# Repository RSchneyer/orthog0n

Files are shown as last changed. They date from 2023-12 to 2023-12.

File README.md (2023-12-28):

# orthog0n

orthog0n keyboard on grey deskmat

The orthog0n is the last keyboard I'll probably design (for the forseeable future). The RGBKB Zen that I had been using for games for like 5 years bit the dust, so I decided to throw together something I had always wanted to get around to making.

As usual, I take no responsibility for anything that doesn't work, or goes wrong when you try to build or use this board. Good luck!

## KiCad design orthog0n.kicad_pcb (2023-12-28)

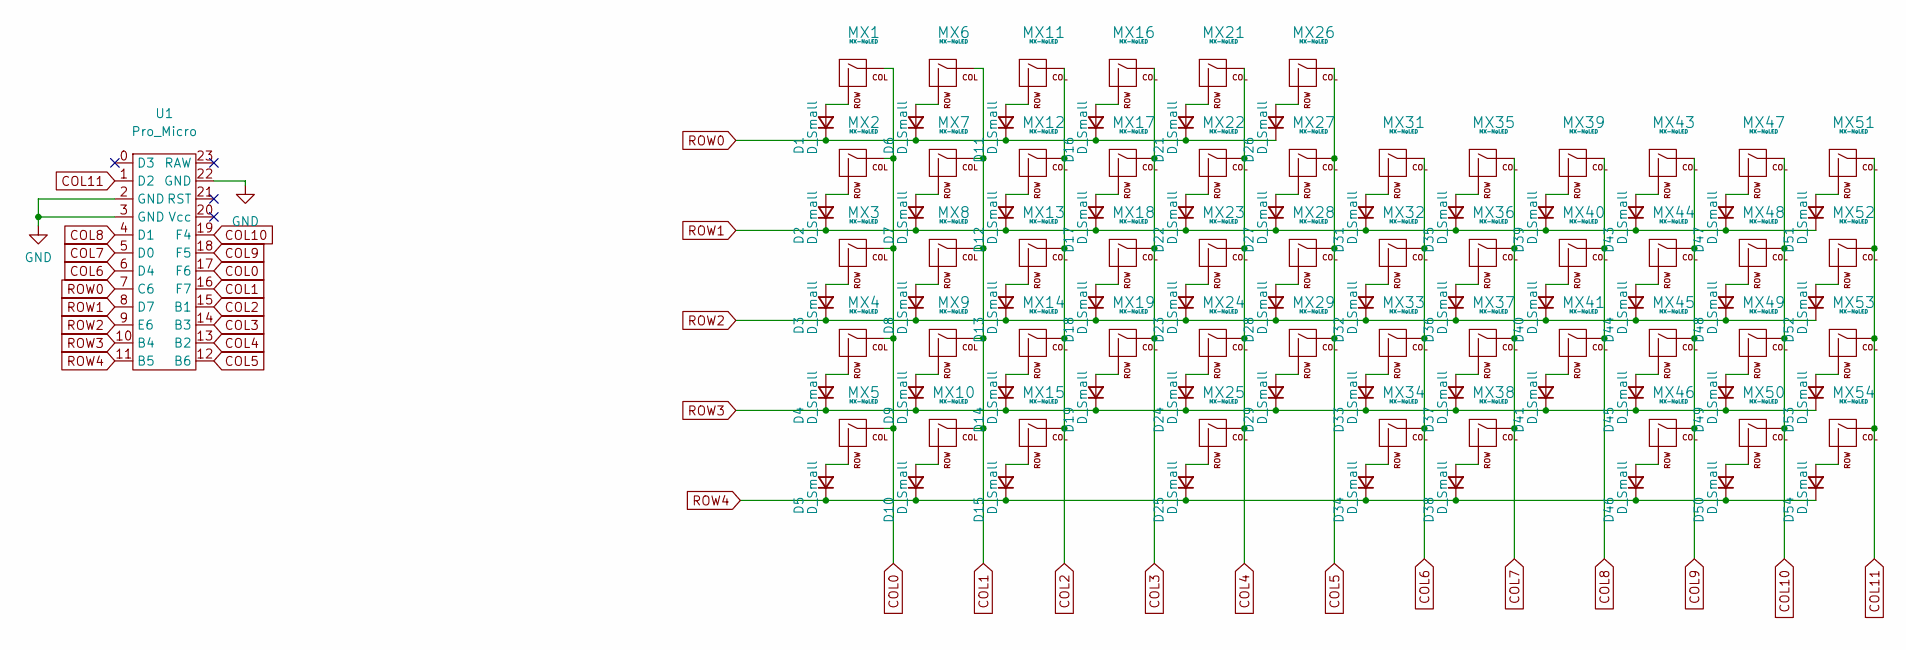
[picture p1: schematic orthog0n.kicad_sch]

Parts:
D1, D2, D3, D4, D5, D6, D7, D8, D9, D10, D11, D12, D13, D14, D15, D16, D17, D18, D19, D21, D22, D23, D24, D25, D26, D27, D28, D29, D31, D32, D33, D34, D35, D36, D37, D38, D39, D40, D41, D43, D44, D45, D46, D47, D48, D49, D50, D51, D52, D53, D54: D_Small; D_DO-35_SOD27_P10.16mm_Horizontal
MX1, MX2, MX3, MX4, MX5, MX15, MX46, MX51, MX52, MX53, MX54: MX-NoLED; SW_Cherry_MX_1.50u_PCB
MX6, MX7, MX8, MX9, MX10, MX11, MX12, MX13, MX14, MX16, MX17, MX18, MX19, MX21, MX22, MX23, MX24, MX26, MX27, MX28, MX29, MX31, MX32, MX33, MX34, MX35, MX36, MX37, MX39, MX40, MX41, MX43, MX44, MX45, MX47, MX48, MX49, MX50: MX-NoLED; SW_Cherry_MX_1.00u_PCB
MX25, MX38: MX-NoLED; SW_Cherry_MX_2.00u_PCB
U1: Pro_Micro; pro_micro

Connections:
COL0: MX1.1 (COL), MX2.1 (COL), MX3.1 (COL), MX4.1 (COL), MX5.1 (COL), U1.17 (F6)
COL1: MX6.1 (COL), MX7.1 (COL), MX8.1 (COL), MX9.1 (COL), MX10.1 (COL), U1.16 (F7)
COL2: MX11.1 (COL), MX12.1 (COL), MX13.1 (COL), MX14.1 (COL), MX15.1 (COL), U1.15 (B1)
COL3: MX16.1 (COL), MX17.1 (COL), MX18.1 (COL), MX19.1 (COL), U1.14 (B3)
COL4: MX21.1 (COL), MX22.1 (COL), MX23.1 (COL), MX24.1 (COL), MX25.1 (COL), U1.13 (B2)
COL5: MX26.1 (COL), MX27.1 (COL), MX28.1 (COL), MX29.1 (COL), U1.12 (B6)
COL6: MX31.1 (COL), MX32.1 (COL), MX33.1 (COL), MX34.1 (COL), U1.6 (D4)
COL7: MX35.1 (COL), MX36.1 (COL), MX37.1 (COL), MX38.1 (COL), U1.5 (D0)
COL8: MX39.1 (COL), MX40.1 (COL), MX41.1 (COL), U1.4 (D1)
COL9: MX43.1 (COL), MX44.1 (COL), MX45.1 (COL), MX46.1 (COL), U1.18 (F5)
COL10: MX47.1 (COL), MX48.1 (COL), MX49.1 (COL), MX50.1 (COL), U1.19 (F4)
COL11: MX51.1 (COL), MX52.1 (COL), MX53.1 (COL), MX54.1 (COL), U1.1 (D2)
GND: U1.2 (GND), U1.3 (GND), U1.22 (GND)
unnamed: D1.2 (A), MX1.2 (ROW)
unnamed: D2.2 (A), MX2.2 (ROW)
unnamed: D3.2 (A), MX3.2 (ROW)
unnamed: D4.2 (A), MX4.2 (ROW)
unnamed: D5.2 (A), MX5.2 (ROW)
unnamed: D6.2 (A), MX6.2 (ROW)
unnamed: D7.2 (A), MX7.2 (ROW)
unnamed: D8.2 (A), MX8.2 (ROW)
unnamed: D9.2 (A), MX9.2 (ROW)
unnamed: D10.2 (A), MX10.2 (ROW)
unnamed: D11.2 (A), MX11.2 (ROW)
unnamed: D12.2 (A), MX12.2 (ROW)
unnamed: D13.2 (A), MX13.2 (ROW)
unnamed: D14.2 (A), MX14.2 (ROW)
unnamed: D15.2 (A), MX15.2 (ROW)
unnamed: D16.2 (A), MX16.2 (ROW)
unnamed: D17.2 (A), MX17.2 (ROW)
unnamed: D18.2 (A), MX18.2 (ROW)
unnamed: D19.2 (A), MX19.2 (ROW)
unnamed: D21.2 (A), MX21.2 (ROW)
unnamed: D22.2 (A), MX22.2 (ROW)
unnamed: D23.2 (A), MX23.2 (ROW)
unnamed: D24.2 (A), MX24.2 (ROW)
unnamed: D25.2 (A), MX25.2 (ROW)
unnamed: D26.2 (A), MX26.2 (ROW)
unnamed: D27.2 (A), MX27.2 (ROW)
unnamed: D28.2 (A), MX28.2 (ROW)
unnamed: D29.2 (A), MX29.2 (ROW)
unnamed: D31.2 (A), MX31.2 (ROW)
unnamed: D32.2 (A), MX32.2 (ROW)
unnamed: D33.2 (A), MX33.2 (ROW)
unnamed: D34.2 (A), MX34.2 (ROW)
unnamed: D35.2 (A), MX35.2 (ROW)
unnamed: D36.2 (A), MX36.2 (ROW)
unnamed: D37.2 (A), MX37.2 (ROW)
unnamed: D38.2 (A), MX38.2 (ROW)
unnamed: D39.2 (A), MX39.2 (ROW)
unnamed: D40.2 (A), MX40.2 (ROW)
unnamed: D41.2 (A), MX41.2 (ROW)
unnamed: D43.2 (A), MX43.2 (ROW)
unnamed: D44.2 (A), MX44.2 (ROW)
unnamed: D45.2 (A), MX45.2 (ROW)
unnamed: D46.2 (A), MX46.2 (ROW)
unnamed: D47.2 (A), MX47.2 (ROW)
unnamed: D48.2 (A), MX48.2 (ROW)
unnamed: D49.2 (A), MX49.2 (ROW)
unnamed: D50.2 (A), MX50.2 (ROW)
unnamed: D51.2 (A), MX51.2 (ROW)
unnamed: D52.2 (A), MX52.2 (ROW)
unnamed: D53.2 (A), MX53.2 (ROW)
unnamed: D54.2 (A), MX54.2 (ROW)
ROW0: D1.1 (K), D6.1 (K), D11.1 (K), D16.1 (K), D21.1 (K), D26.1 (K), U1.7 (C6)
ROW1: D2.1 (K), D7.1 (K), D12.1 (K), D17.1 (K), D22.1 (K), D27.1 (K), D31.1 (K), D35.1 (K), D39.1 (K), D43.1 (K), D47.1 (K), D51.1 (K), U1.8 (D7)
ROW2: D3.1 (K), D8.1 (K), D13.1 (K), D18.1 (K), D23.1 (K), D28.1 (K), D32.1 (K), D36.1 (K), D40.1 (K), D44.1 (K), D48.1 (K), D52.1 (K), U1.9 (E6)
ROW3: D4.1 (K), D9.1 (K), D14.1 (K), D19.1 (K), D24.1 (K), D29.1 (K), D33.1 (K), D37.1 (K), D41.1 (K), D45.1 (K), D49.1 (K), D53.1 (K), U1.10 (B4)
ROW4: D5.1 (K), D10.1 (K), D15.1 (K), D25.1 (K), D34.1 (K), D38.1 (K), D46.1 (K), D50.1 (K), D54.1 (K), U1.11 (B5)

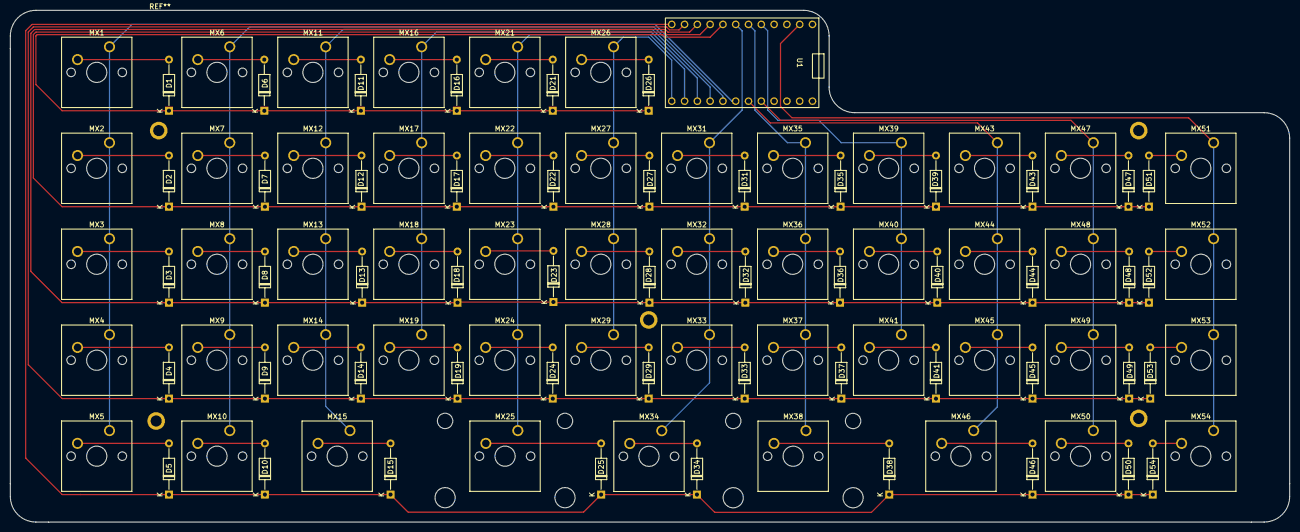
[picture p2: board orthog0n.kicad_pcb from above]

Board: 2 copper layers, 254.0 x 101.6 mm, 103 parts (0 on the bottom side), 69 nets.

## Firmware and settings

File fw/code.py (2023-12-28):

import board
dir(board)
from kmk.kmk_keyboard import KMKKeyboard
from kmk.keys import KC
from kmk.scanners import DiodeOrientation
from kmk.modules.layers import Layers

keyboard = KMKKeyboard()
keyboard.modules.append(Layers())
keyboard.col_pins = (board.A1, board.A0, board.SCK, board.MISO, board.MOSI, board.D10, board.D4, board.D3, board.D2, board.A2, board.A3, board.D1)
keyboard.row_pins = (board.D5, board.D6, board.D7, board.D8, board.D9,)
keyboard.diode_orientation = DiodeOrientation.COL2ROW

LAYER02 = KC.LT(2, KC.SPC)
LAYER03 = KC.LT(3, KC.SPC)
NAVLAYR = KC.MO(4)

keyboard.keymap = [
    # typing layer
    [
        KC.ESC,  KC.N1,   KC.N2,   KC.N3, KC.N4,  KC.N5, KC.NO,   KC.NO,   KC.NO,   KC.NO,  KC.NO,   KC.NO,\
        KC.TAB,  KC.Q,    KC.W,    KC.E,  KC.R,   KC.T,  KC.Y,    KC.U,    KC.I,    KC.O,   KC.P,    KC.BSPC,\
        KC.LCTL, KC.A,    KC.S,    KC.D,  KC.F,   KC.G,  KC.H,    KC.J,    KC.K,    KC.L,   KC.SCLN, KC.QUOT,\
        KC.LSFT, KC.Z,    KC.X,    KC.C,  KC.V,   KC.B,  KC.N,    KC.M,    KC.COMM, KC.DOT, KC.SLSH, KC.ENT,\
        KC.LCTL, KC.LWIN, KC.LALT, KC.NO, LAYER03, KC.NO, NAVLAYR, LAYER02, KC.NO,   KC.NO,  KC.NO,   KC.TG(1),
    ],
    # gaming layer
    [
        KC.ESC,  KC.N1,   KC.N2,   KC.N3, KC.N4,  KC.N5, KC.NO,   KC.NO,   KC.NO,   KC.NO,  KC.NO,   KC.NO,\
        KC.TAB,  KC.Q,    KC.W,    KC.E,  KC.R,   KC.T,  KC.Y,    KC.U,    KC.I,    KC.O,   KC.P,    KC.BSPC,\
        KC.LCTL, KC.A,    KC.S,    KC.D,  KC.F,   KC.G,  KC.H,    KC.J,    KC.K,    KC.L,   KC.SCLN, KC.QUOT,\
        KC.LSFT, KC.Z,    KC.X,    KC.C,  KC.V,   KC.B,  KC.N,    KC.M,    KC.COMM, KC.DOT, KC.SLSH, KC.ENT,\
        KC.LCTL, KC.ESC, KC.LALT, KC.NO, KC.SPC, KC.NO, NAVLAYR, LAYER02, KC.NO,   KC.NO,  KC.NO,   KC.TG(0),
    ],
    # numbers layer and -=[]\
    [
        KC.TRNS, KC.TRNS, KC.TRNS, KC.TRNS, KC.TRNS, KC.TRNS, KC.NO,   KC.NO,   KC.NO,   KC.NO,   KC.NO,   KC.NO,\
        KC.GRV,  KC.N1,   KC.N2,   KC.N3,   KC.N4,   KC.N5,   KC.N6,   KC.N7,   KC.N8,   KC.N9,   KC.N0,   KC.NO,\
        KC.TRNS, KC.TRNS, KC.TRNS, KC.TRNS, KC.TRNS, KC.TRNS, KC.TRNS, KC.MINS, KC.EQL,  KC.LBRC, KC.RBRC, KC.BSLS,\
        KC.TRNS, KC.TRNS, KC.TRNS, KC.TRNS, KC.TRNS, KC.TRNS, KC.TRNS, KC.TRNS, KC.TRNS, KC.TRNS, KC.TRNS, KC.TRNS,\
        KC.TRNS, KC.TRNS, KC.TRNS, KC.TRNS, KC.LSFT, KC.TRNS, KC.TRNS, KC.TRNS, KC.TRNS, KC.TRNS, KC.TRNS, KC.TRNS,
    ],
    # shifted numbers layer
    [
        KC.TRNS, KC.TRNS, KC.TRNS, KC.TRNS, KC.TRNS, KC.TRNS, KC.NO,   KC.NO,   KC.NO,   KC.NO,   KC.NO,   KC.NO,\
        KC.GRV,  KC.EXLM, KC.AT,   KC.HASH, KC.DLR,  KC.PERC, KC.CIRC, KC.AMPR, KC.ASTR, KC.LPRN, KC.RPRN, KC.NO,\
        KC.TRNS, KC.TRNS, KC.TRNS, KC.TRNS, KC.TRNS, KC.TRNS, KC.TRNS, KC.UNDS, KC.PLUS, KC.LCBR, KC.RCBR, KC.PIPE,\
        KC.TRNS, KC.TRNS, KC.TRNS, KC.TRNS, KC.TRNS, KC.TRNS, KC.TRNS, KC.TRNS, KC.TRNS, KC.TRNS, KC.TRNS, KC.TRNS,\
        KC.TRNS, KC.TRNS, KC.TRNS, KC.TRNS, KC.LSFT, KC.TRNS, KC.TRNS, KC.TRNS, KC.TRNS, KC.TRNS, KC.TRNS, KC.TRNS,
    ],
    # navigation + fkey layer
    [
        KC.TRNS, KC.TRNS, KC.TRNS, KC.TRNS, KC.TRNS, KC.TRNS, KC.NO,   KC.NO,   KC.NO,   KC.NO,   KC.NO,   KC.NO,\
        KC.TRNS, KC.F1,   KC.F2,   KC.F3,   KC.F4,   KC.TRNS, KC.TRNS, KC.TRNS, KC.UP,   KC.TRNS, KC.TRNS, KC.TRNS,\
        KC.CAPS, KC.F5,   KC.F6,   KC.F7,   KC.F8,   KC.TRNS, KC.TRNS, KC.LEFT, KC.DOWN, KC.RGHT, KC.TRNS, KC.TRNS,\
        KC.TRNS, KC.F9,   KC.F10,  KC.F11,  KC.F12,  KC.TRNS, KC.TRNS, KC.TRNS, KC.TRNS, KC.TRNS, KC.TRNS, KC.TRNS,\
        KC.TRNS, KC.TRNS, KC.TRNS, KC.TRNS, KC.TRNS, KC.TRNS, KC.TRNS, KC.TRNS, KC.TRNS, KC.TRNS, KC.TRNS, KC.TRNS,
    ]
]

if __name__ == '__main__':
    print('hello world!')
    keyboard.go()
